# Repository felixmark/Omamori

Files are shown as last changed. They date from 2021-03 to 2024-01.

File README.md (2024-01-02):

# Omamori
Omamori is a solar-powered LED lucky and protector charm.<br>
I have got the motivation to realize this project during my time in university, when I first designed PCBs, even though I had the idea for much longer. At first, I was using Altium Designer, which was used by my university. Later since version 2.0 I switched to KiCad, which is a gem of software, which was recommended to me by Andreas.<br>
A huge thank you for helping me with soldering, designing, listening and keeping my motivation up to:<br>
Andreas, Markus, Patrick, Anna-Lena, Flopsi, Stephan and many others! ♥️<br>
<br>

## Programming

Program ATTiny 1626 via UPDI pins on the back of the PCB.  
Set the internal clock to 1MHz and use a low uploading BAUD to make sure the microcontroller can keep up.  

<br><br>

# History

A version History of the Omamori project.

[Version 0.3.1](#Version-030) \
[Version 0.3.0](#Version-030) \
[Version 0.2.1](#Version-021) \
[Version 0.2.0](#Version-020) \
[Version 0.1.0](#Version-010)
<br><br>

## Version 0.3.1

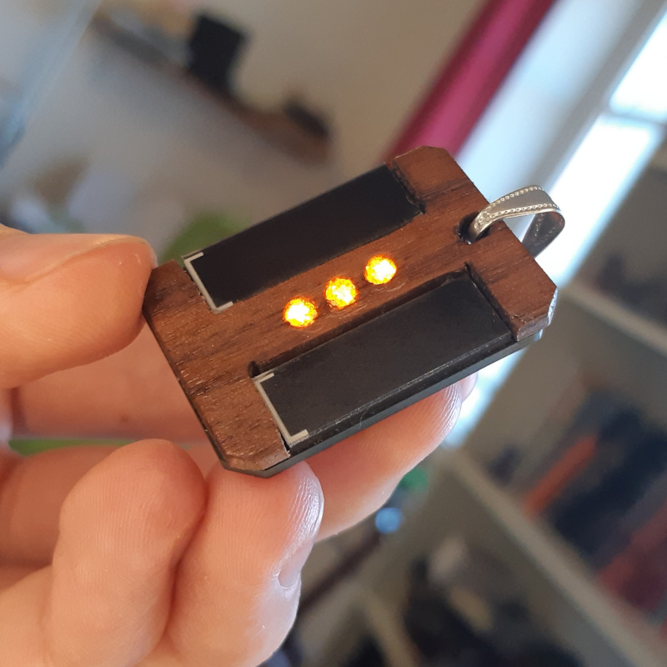
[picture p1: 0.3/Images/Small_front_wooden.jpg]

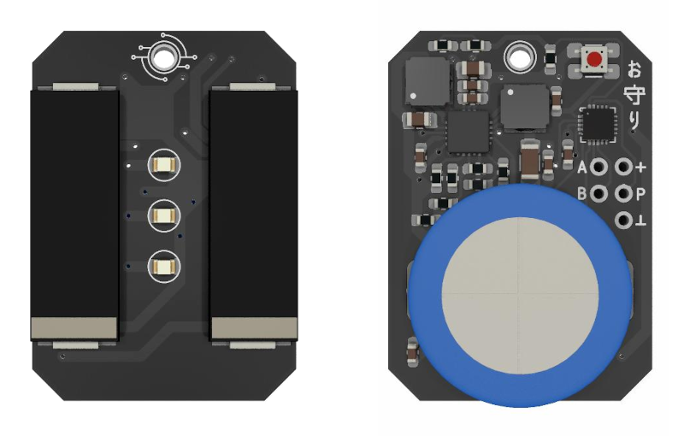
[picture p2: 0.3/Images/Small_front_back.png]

\
Hardware as in Version 0.3.0 except that a few capacitors are closer to the BQ25570 and I added a few other transistors for stability. Everything is working as expected.  
I consider this the final version for now.  

<br><br>

## Version 0.3.0

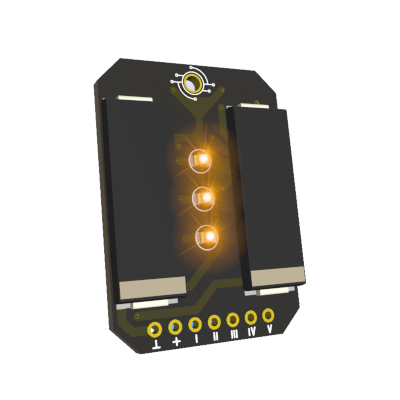
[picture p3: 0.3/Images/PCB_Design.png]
PCB v3.0

\
**MCU:** 1x ATTiny 1626 \
**Energy Harvester:** 1x BQ25570 \
**Solar Cells:** 2x KXOB25-05X3F \
**LEDS:** 3x Orange 0805 SMD LED

<br><br>

## Version 0.2.1

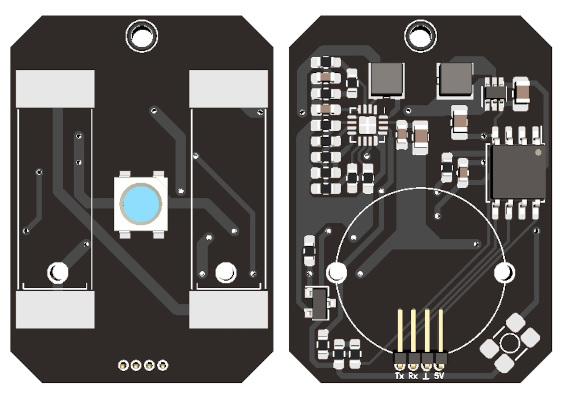
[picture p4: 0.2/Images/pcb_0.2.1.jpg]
PCB v2.1

\
Hardware as in Version 0.2.0 except a few resistors instead of the diode for measuring battery voltage and an IRLML2502 N-Channel MOSFET for switching the 5V boost converter.
This version works, but has a very short supercap lifetime. Therefore the next version has to be a lot more efficient.

<br><br>

## Version 0.2.0
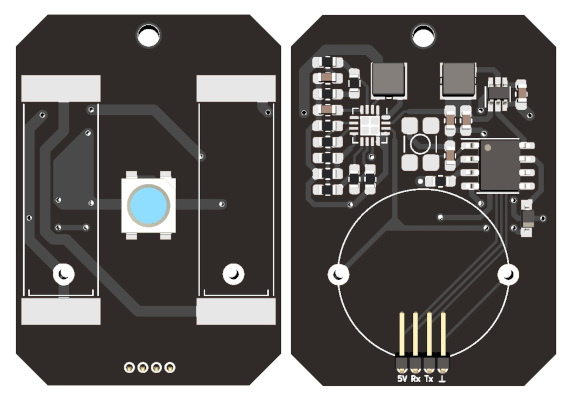
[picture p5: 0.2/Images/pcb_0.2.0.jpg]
PCB v2.0

\
**MCU:** 1x ATTiny 85 \
**Energy Harvester:** 1x BQ25504 \
**Solar Cells:** 2x KXOB25-05X3F \
**Boost Converter:** 1x TPS61222 \
**LED:** 1x SK6812 programmable RGBW LED

### Energy Harvester (BQ25504) properties

```
V_REF_SAMP    = 3.33V (R_OC1 = 6.2 MOhm + 10 MOhm = 16.2 MOhm, R_OC2 = 3.9 MOhm)
V_BAT_UV      = 2.21V (R_UV1 = 5.6 MOhm, R_UV2 = 4.3MOhm)
V_BAT_OK      = 2.27V (R_OK1 = 3.3 MOhm, R_OK2 = 2.7 MOhm, R_OK3 = 3.3 MOhm)
V_BAT_OK_HYST = 3.52V
V_BAT_OV      = 5.42V (R_OV1 = 3.6 MOhm, R_OV2 = 6.8 MOhm)
```

<br><br>

## Version 0.1.0
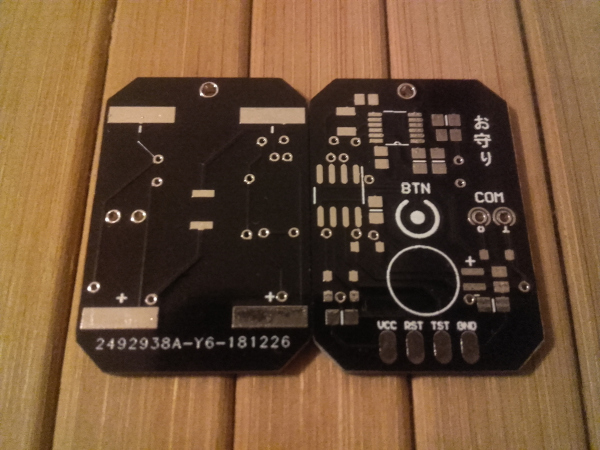
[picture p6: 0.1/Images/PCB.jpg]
PCB v1.0

\
**MCU:** 1x MSP430G2210 \
**Energy Harvester:** 1x LTC3105 \
**Solar Cells:** 2x KXOB22-04X3L 1.5Vmpp \
**LED:** 1x Natural White LED

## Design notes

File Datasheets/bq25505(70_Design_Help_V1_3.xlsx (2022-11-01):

User Input | VBIAS | 1.21 | V
Fixed
 | Comparator threshold for VSTOR of charger. |  |  |  |  | Comparator threshold voltages indicating when |  |  |  |  | For the bq25570 only, comparator threshold |  |  |  |  | Maximum power point threshold, e.g. ~0.7-0.8 of
 | Typically the max storage element voltage, |  |  |  |  | VSTOR has risen above VBAT_OK_HYST or fallen |  |  |  |  | for VOUT of buck converter. |  |  |  |  | solar panel's open circuit voltage.
 | e.g. 4.2V for LiIon battery. |  |  |  |  | below VBAT_OK.
 | VBAT_UV < VBAT_OV < 5.5V |  |  |  |  | VBAT_OV > VBAT_OK_HYST > VBAT_UV |  |  |  |  | 1.3V < VOUT < VBAT_OV |  |  |  |  | MPPT
Desired |  |  |  |  |  | RSUM1 | 13 | MW |  |  |  |  |  |  |  | RSUM1 | 20 | MW
Desired | RSUM1 | 13 | MW |  |  | VBAT_OK | 2 | V | > VBAT_UV |  | RSUM1 | 13 | MW |  |  | VIN_DC(OC) | 3 | V | Open Circuit Volts
Desired | VBAT_OV | 5.5 | V |  |  | VBAT_OK_HYST | 2.5 | V | > VBAT_OK |  | VOUT | 1.8 | V |  |  | VREF_SAMP | 2.4 | V | MPP voltage
 |  |  |  |  |  |  |  | closest 1% resistor1 |  |  |  |  |  |  |  |  |  | closest 1% resistor1
 |  |  | closest 1% resistor1 |  |  |  | Exact | < | > |  |  |  | closest 1% resistor1 |  |  |  | Exact | < | >
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

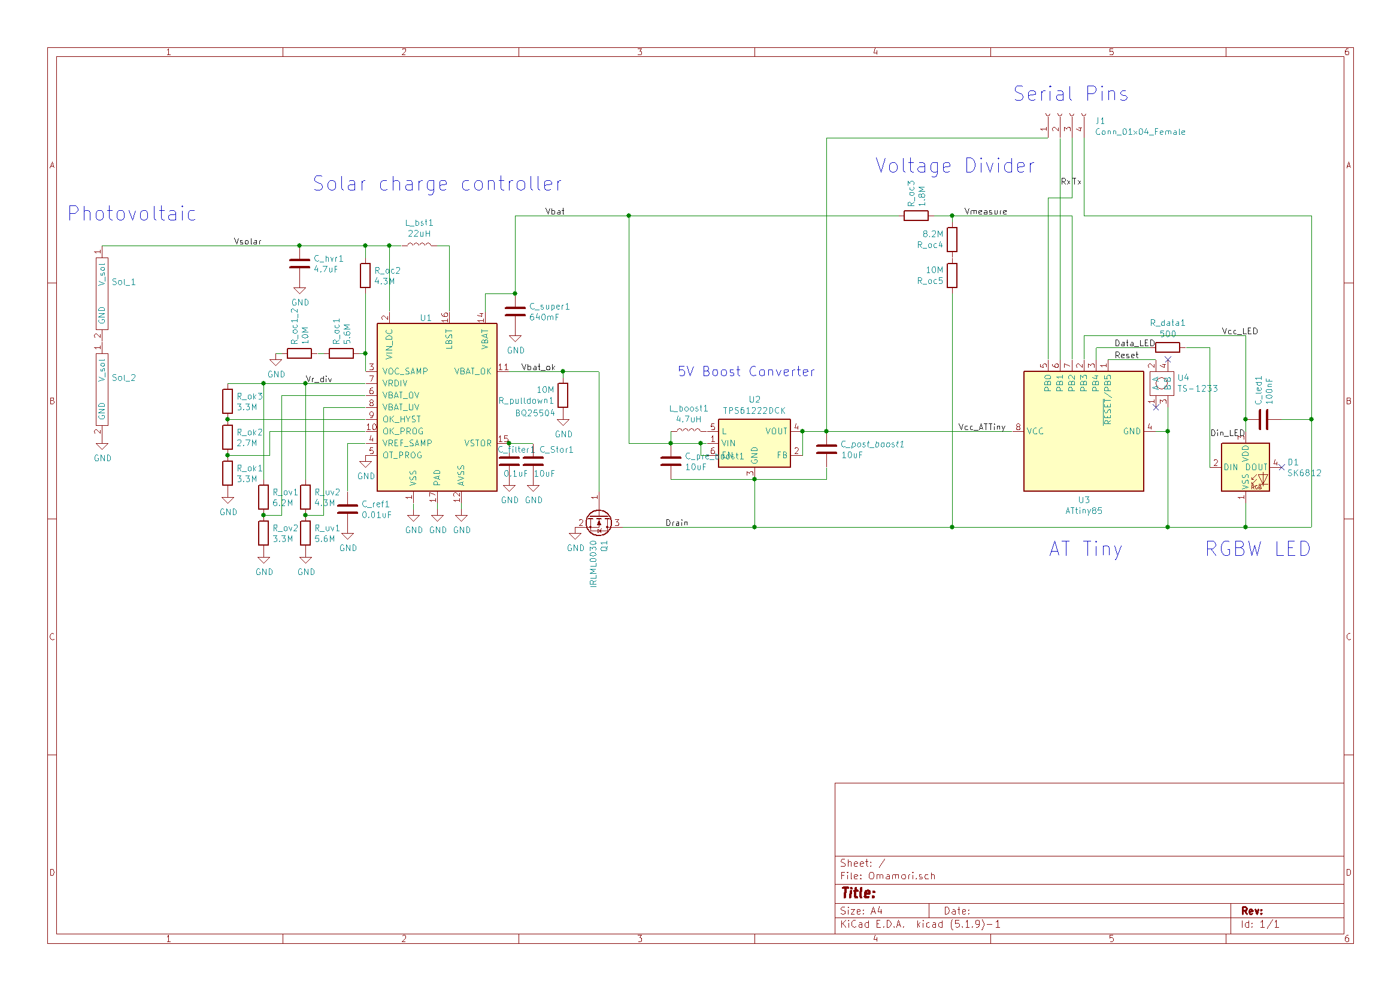
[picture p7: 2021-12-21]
0.2/Images/schematic_0.2.1.png

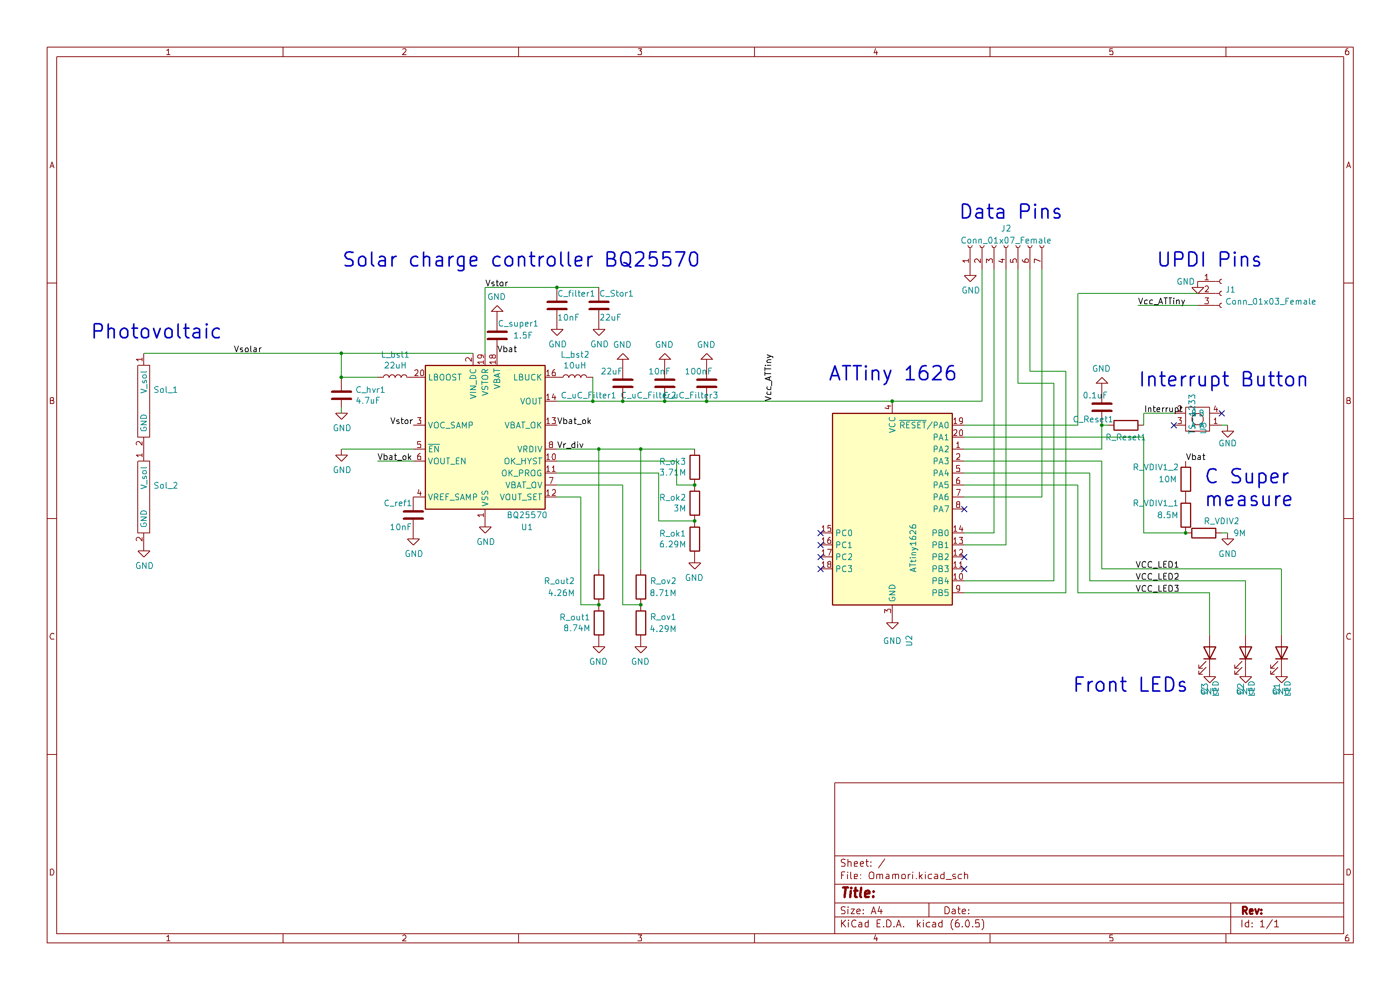
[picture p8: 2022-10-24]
0.3/Images/Schematic.png

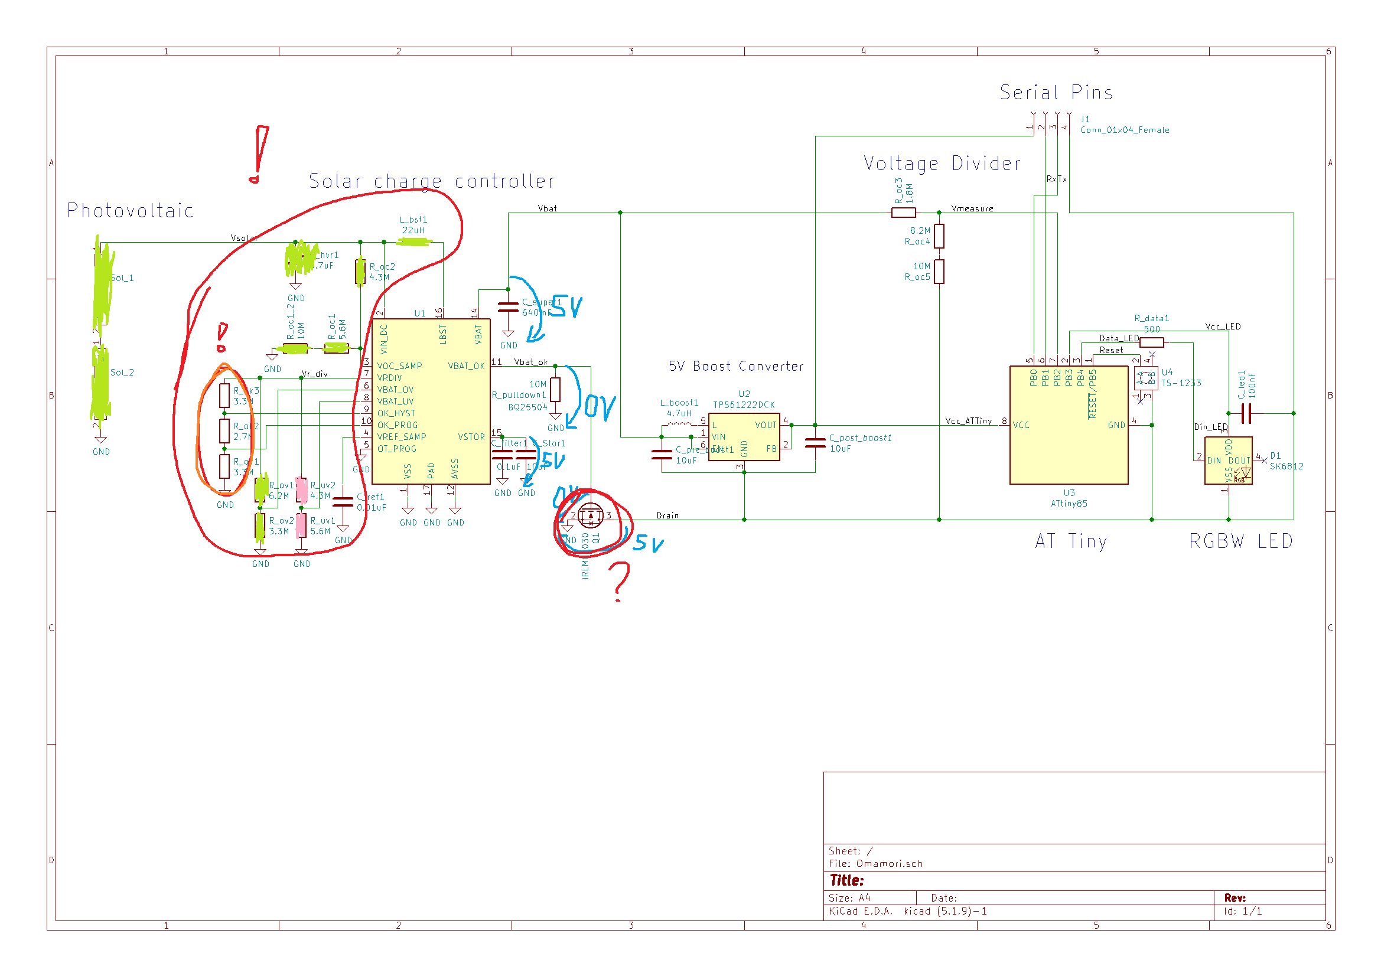
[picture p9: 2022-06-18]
0.2/Images/schematic_0.2.1 - Kopie.png

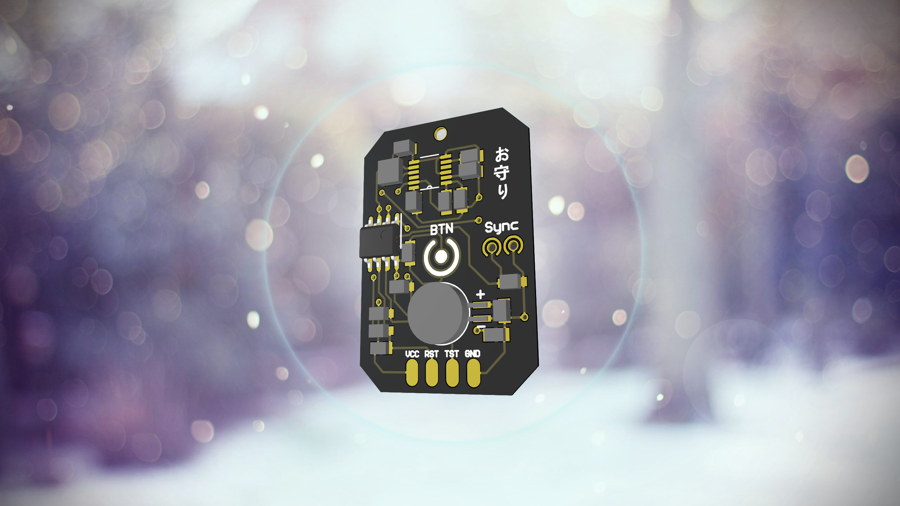
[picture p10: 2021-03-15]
0.1/Images/PCB_design.jpg

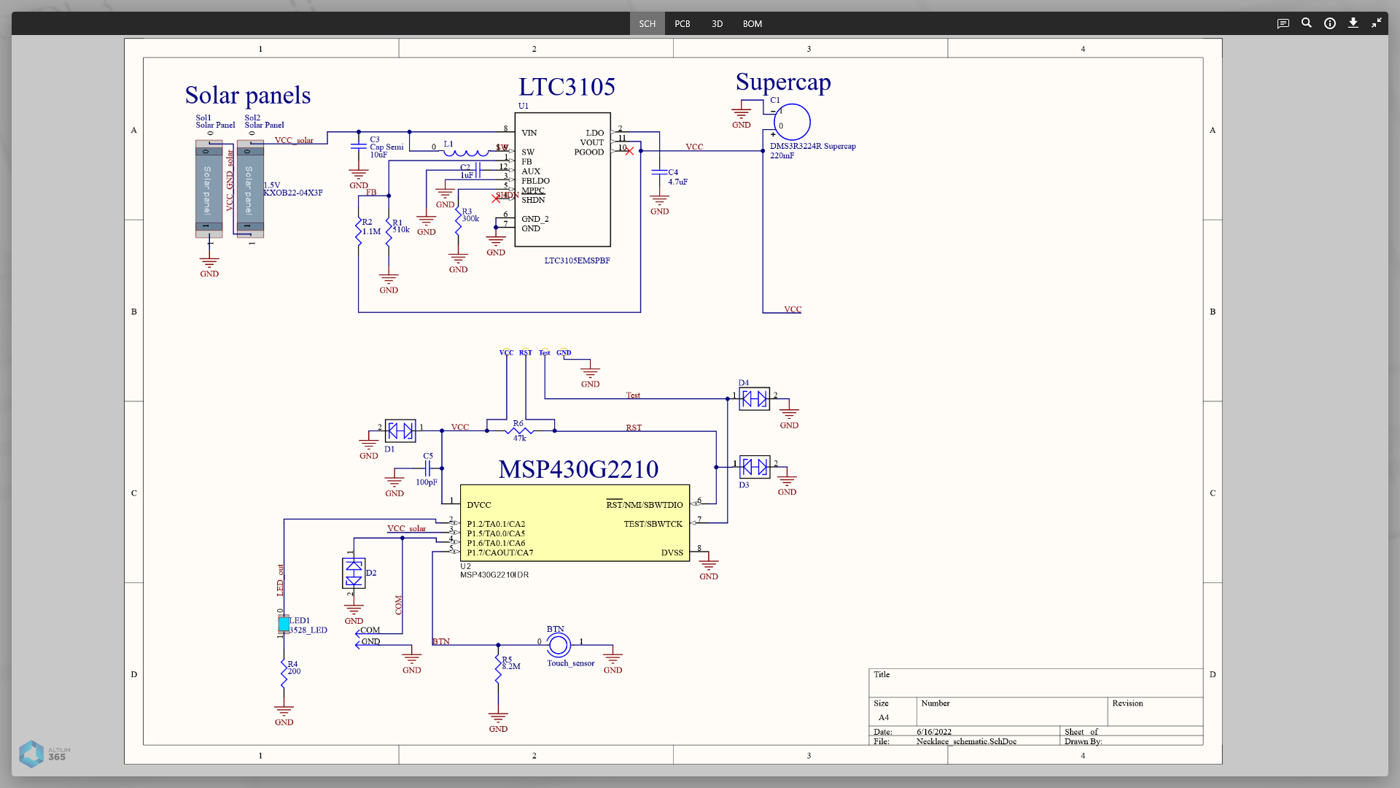
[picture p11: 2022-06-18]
0.1/Images/Schematic.png

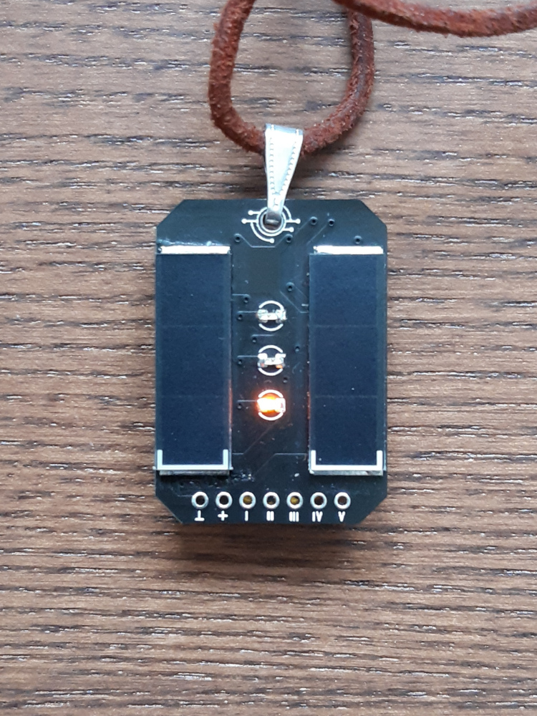
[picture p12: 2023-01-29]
0.3/Images/photo_front.jpg

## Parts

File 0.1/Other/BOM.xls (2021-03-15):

Comment | Designator | Footprint | LibRef | Quantity | Value
Touch_sensor | BTN | Touch_sensor | Touch_sensor | 1
DMS3R3224R Supercap | C1 | DMS3R3224R Supercap | DMS3R3224R Supercap | 1
Capacitor | C2, C3, C4, C5 | C0805 | Cap Semi | 4 | 1uF, 10uF, 4.7uF, 100pF
COM | COM | Synchronizer | COM | 1
TVS Diode | D1, D2, D3, D4 | ESD Protection Diode | ESD-Diode | 4
L | L1 | Inductivity | Inductivity | 1
LED | LED1 | 3528_LED | 3528_LED | 1
R | R1, R2, R3, R4, R5, R6 | 0805_N | Res3 | 6 | 510k, 1.1M, 300k, 200, 8.2M, 47k
Solar_panel | Sol1, Sol2 | Solarzelle | Solar_Panel | 2
LTC3105EMSPBF | U1 | SOP65P490X110-12N | LTC3105EMSPBF | 1
MSP430G2210IDR | U2 | MSP430G2210 | MSP430G2210IDR | 1
Program_connector | U3 | Program_connector | Program_connector | 1

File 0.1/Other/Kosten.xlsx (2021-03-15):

Kosten
Teil | Gekauft bei | Anzahl | Preis | Summe | Gesamt | Pro Stück
Korchip DMS3R3224R Doppelschicht-Kondensator 0.22 F 3.3 V (Ø x H) 6.8 mm x 1.4 mm 1 St. | Conrad | 1 | €1.29 | €1.29 | €48.70 | €14.64
Texas Instruments MSP430G2210ID Embedded-Mikrocontroller SOIC-8 16-Bit 16 MHz Anzahl I/O 4 | Conrad | 1 | €1.49 | €1.49
Solarzelle IXYS KXOB22-04X3L=KXOB22-04X3F 1.5 V/DC 44 mA 1 St. (L x B x H) 22 x 7 x 1.8 mm | Conrad | 2 | €4.19 | €8.38
SMD LED Ice blue 3528 | Aliexpress | 50 | €0.02 | €1.24
LTC3105 400mA Step-Up DC/DC Converter with Maximum Power Point Control and 250mV Start-Up | Aliexpress | 5 | €2.85 | €14.25
Bourns SRN3010-100M Induktivität abgeschirmt SMD 10 µH 0.9 A | Conrad | 5 | €0.39 | €1.95
Infineon Technologies IRLML2502TRPBF MOSFET 1 N-Kanal 1.25 W SOT-23 | Conrad | 5 | €0.22 | €1.10
PCB | Elecrow | 10 | €1.90 | €19.00
 |  |  |  | €0.00
 |  |  |  | €0.00
 |  |  |  | €0.00
 |  |  |  | €0.00
 |  |  |  | €0.00
 |  |  |  | €0.00
 |  |  |  | €0.00
 |  |  |  | €0.00
 |  |  |  | €0.00
 |  |  |  | €0.00
 |  |  |  | €0.00
 |  |  |  | €0.00
 |  |  |  | €0.00
 |  |  |  | €0.00
 |  |  |  | €0.00
 |  |  |  | €0.00
 |  |  |  | €0.00
 |  |  |  | €0.00
 |  |  |  | €0.00
 |  |  |  | €0.00
 |  |  |  | €0.00
 |  |  |  | €0.00
 |  |  |  | €0.00
 |  |  |  | €0.00
 |  |  |  | €0.00
 |  |  |  | €0.00
 |  |  |  | €0.00
 |  |  |  | €0.00
 |  |  |  | €0.00
 |  |  |  | €0.00
 |  |  |  | €0.00
 |  |  |  | €0.00
 |  |  |  | €0.00

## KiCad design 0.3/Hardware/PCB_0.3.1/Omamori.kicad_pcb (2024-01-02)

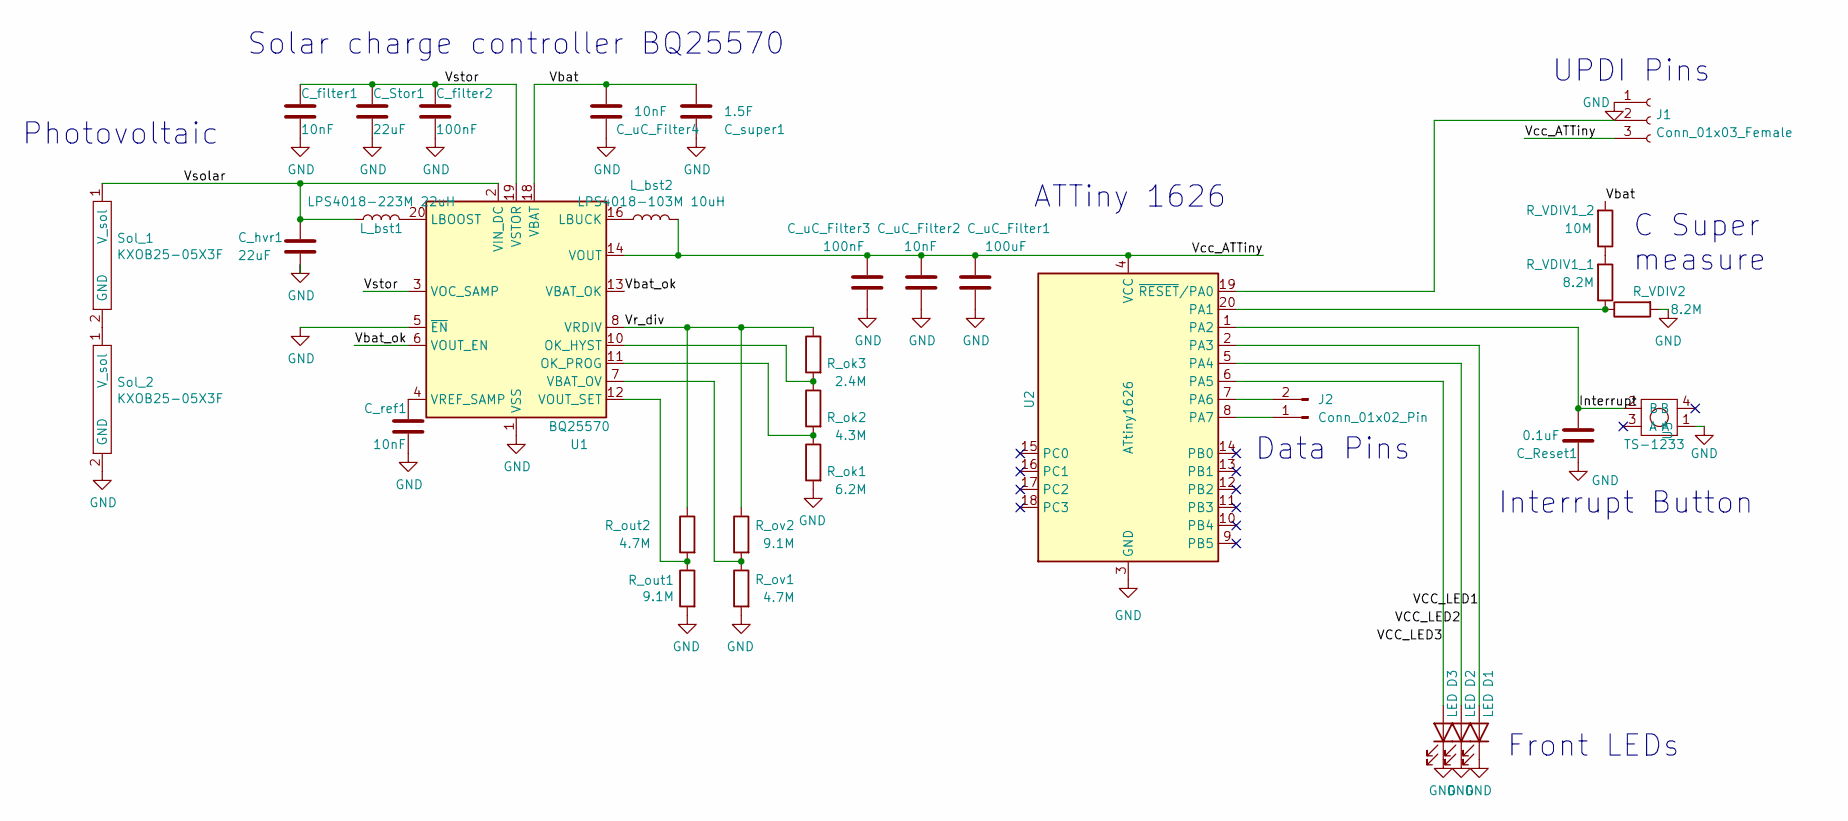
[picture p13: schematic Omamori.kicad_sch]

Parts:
C_Reset1: 0.1uF; C_0603_1608Metric_Pad1.08x0.95mm_HandSolder
C_Stor1: 22uF; C_0805_2012Metric_Pad1.18x1.45mm_HandSolder
C_filter1: 10nF; C_0603_1608Metric_Pad1.05x0.95mm_HandSolder
C_filter2: 100nF; C_0603_1608Metric_Pad1.08x0.95mm_HandSolder
C_hvr1: 22uF; C_0805_2012Metric_Pad1.18x1.45mm_HandSolder
C_ref1: 10nF; C_0603_1608Metric_Pad1.08x0.95mm_HandSolder
C_super1: 1.5F; Supercap_1F
C_uC_Filter1: 100uF; C_1206_3216Metric_Pad1.33x1.80mm_HandSolder
C_uC_Filter2, C_uC_Filter4: 10nF; C_0603_1608Metric_Pad1.08x0.95mm_HandSolder
C_uC_Filter3: 100nF; C_0603_1608Metric_Pad1.08x0.95mm_HandSolder
D1, D2, D3: LED; LED_0805_2012Metric
J1: Conn_01x03_Female; PinHeader_1x03_P2.54mm_Vertical
J2: Conn_01x02_Pin; PinHeader_1x02_P2.54mm_Vertical
L_bst1: LPS4018-223M 22uH; L_Coilcraft_LPS4018
L_bst2: LPS4018-103M 10uH; L_Coilcraft_LPS4018
R_VDIV1_1, R_VDIV2: 8.2M; R_0603_1608Metric_Pad0.98x0.95mm_HandSolder
R_VDIV1_2: 10M; R_0603_1608Metric_Pad0.98x0.95mm_HandSolder
R_ok1: 6.2M; R_0603_1608Metric_Pad1.05x0.95mm_HandSolder
R_ok2: 4.3M; R_0603_1608Metric_Pad1.05x0.95mm_HandSolder
R_ok3: 2.4M; R_0603_1608Metric_Pad1.05x0.95mm_HandSolder
R_out1: 9.1M; R_0603_1608Metric_Pad1.05x0.95mm_HandSolder
R_out2: 4.7M; R_0603_1608Metric_Pad1.05x0.95mm_HandSolder
R_ov1: 4.7M; R_0603_1608Metric_Pad1.05x0.95mm_HandSolder
R_ov2: 9.1M; R_0603_1608Metric_Pad1.05x0.95mm_HandSolder
Sol_1, Sol_2: KXOB25-05X3F
U1: BQ25570; QFN-20-1EP_3.5x3.5mm_P0.5mm_EP2x2mm
U2: ATtiny1626; VQFN-20-1EP_3x3mm_P0.4mm_EP1.7x1.7mm
U3: TS-1233

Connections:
/Interrupt: C_Reset1.2, U2.1 (PA2), U3.2 (B)
/VCC_LED1: D1.2 (A), U2.2 (PA3)
/VCC_LED2: D2.2 (A), U2.5 (PA4)
/VCC_LED3: D3.2 (A), U2.6 (PA5)
/Vbat: C_super1.2, C_uC_Filter4.1, R_VDIV1_2.2, U1.18 (VBAT)
/Vbat_ok: U1.6 (VOUT_EN), U1.13 (VBAT_OK)
/Vcc_ATTiny: C_uC_Filter1.1, C_uC_Filter2.1, C_uC_Filter3.1, J1.3, L_bst2.2, U1.14 (VOUT), U2.4 (VCC)
/Vr_div: R_ok3.1, R_out2.1, R_ov2.1, U1.8 (VRDIV)
/Vsolar: C_hvr1.1, L_bst1.1, Sol_1.1 (V_sol), U1.2 (VIN_DC)
/Vstor: C_Stor1.1, C_filter1.1, C_filter2.1, U1.3 (VOC_SAMP), U1.19 (VSTOR)
GND: C_Reset1.1, C_Stor1.2, C_filter1.2, C_filter2.2, C_hvr1.2, C_ref1.2, C_super1.1, C_uC_Filter1.2, C_uC_Filter2.2, C_uC_Filter3.2, C_uC_Filter4.2, D1.1 (K), D2.1 (K), D3.1 (K), J1.1, R_VDIV2.2, R_ok1.2, R_out1.2, R_ov1.2, Sol_2.2 (GND), U1.1 (VSS), U1.5 (~EN), U1.9 (VSS), U1.15 (VSS), U1.17 (VSS), U1.21 (VSS), U2.3 (GND), U2.21 (GND), U3.1 (A)
unnamed: J1.2, U2.19 (~RESET/PA0)
unnamed: J2.1, U2.8 (PA7)
unnamed: J2.2, U2.7 (PA6)
unnamed: R_VDIV1_1.2, R_VDIV1_2.1
unnamed: Sol_1.2 (GND), Sol_2.1 (V_sol)
unnamed: L_bst1.2, U1.20 (LBOOST)
unnamed: L_bst2.1, U1.16 (LBUCK)
unnamed: R_ok2.1, R_ok3.2, U1.10 (OK_HYST)
unnamed: R_ok1.1, R_ok2.2, U1.11 (OK_PROG)
unnamed: R_ov1.1, R_ov2.2, U1.7 (VBAT_OV)
unnamed: R_out1.1, R_out2.2, U1.12 (VOUT_SET)
unnamed: C_ref1.1, U1.4 (VREF_SAMP)
unnamed: R_VDIV1_1.1, R_VDIV2.1, U2.20 (PA1)

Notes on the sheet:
UPDI Pins
C Super measure
Front LEDs
Photovoltaic
Data Pins
Interrupt Button
Solar charge controller BQ25570
ATTiny 1626

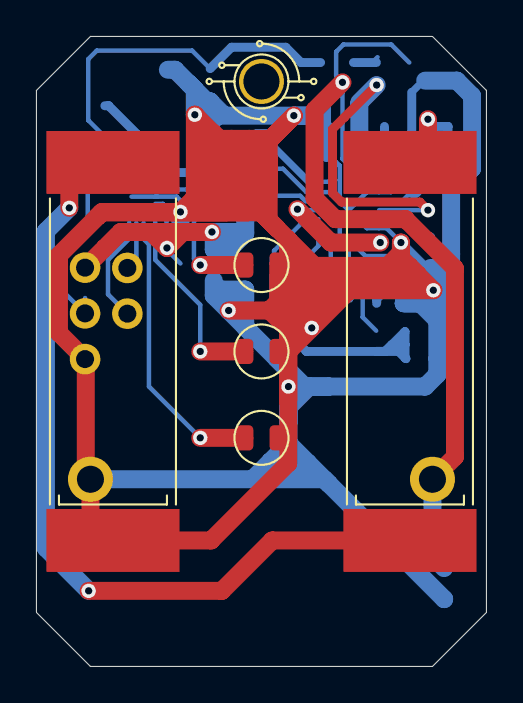
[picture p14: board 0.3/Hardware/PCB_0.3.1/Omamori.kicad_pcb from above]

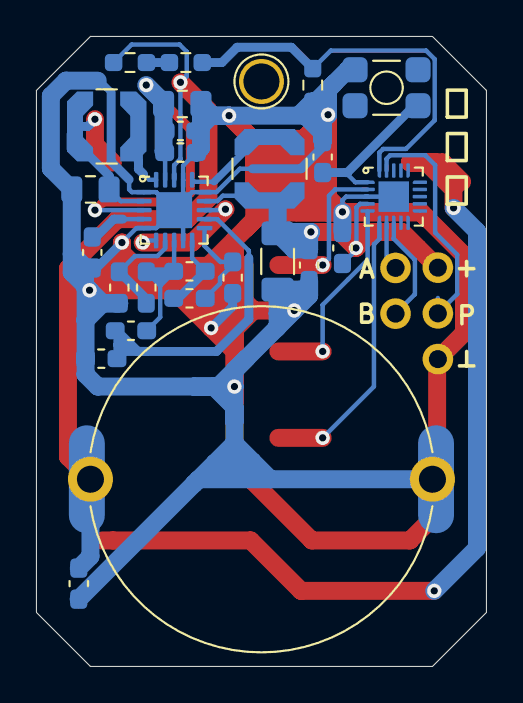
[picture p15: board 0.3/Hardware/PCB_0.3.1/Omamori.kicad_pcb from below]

Board: 2 copper layers, 25.0 x 35.0 mm, 33 parts (28 on the bottom side), 24 nets.

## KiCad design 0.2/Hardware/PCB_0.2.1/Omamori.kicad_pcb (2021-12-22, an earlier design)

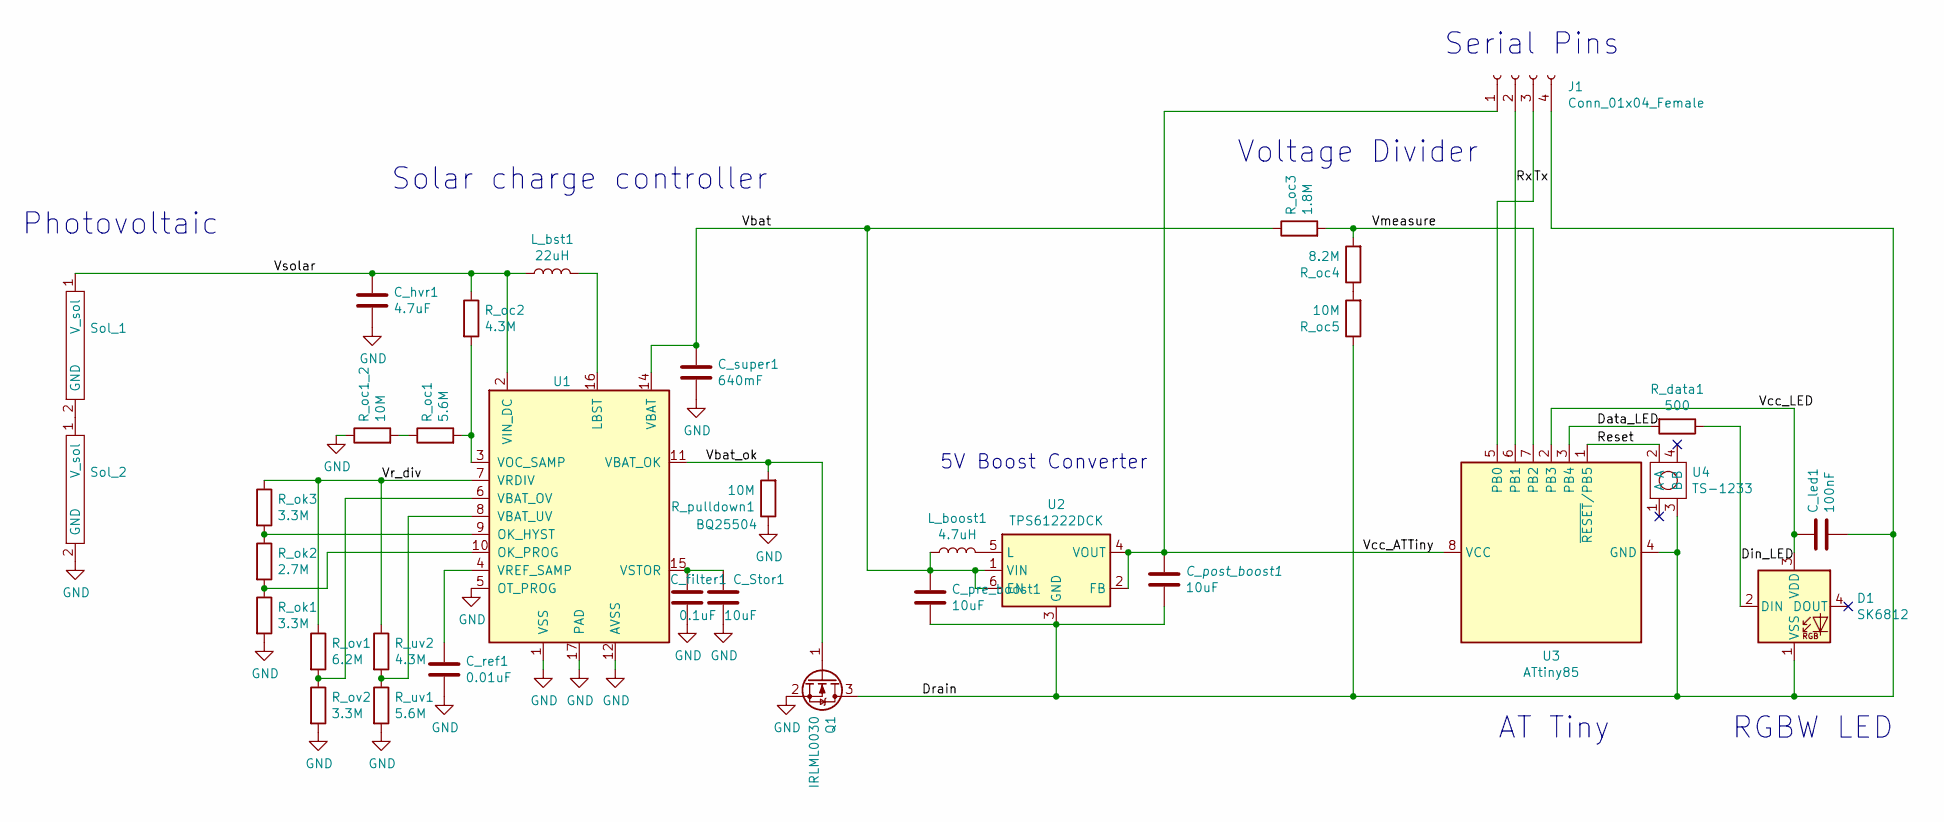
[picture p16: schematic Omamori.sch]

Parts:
C_Stor1: 10uF; C_0805_2012Metric_Pad1.18x1.45mm_HandSolder
C_filter1: 0.1uF; C_0603_1608Metric_Pad1.05x0.95mm_HandSolder
C_hvr1: 4.7uF; C_0805_2012Metric_Pad1.18x1.45mm_HandSolder
C_led1: 100nF; C_0603_1608Metric_Pad1.05x0.95mm_HandSolder
C_post_boost1: 10uF; C_0805_2012Metric_Pad1.18x1.45mm_HandSolder
C_pre_boost1: 10uF; C_0805_2012Metric_Pad1.18x1.45mm_HandSolder
C_ref1: 0.01uF; C_0603_1608Metric_Pad1.05x0.95mm_HandSolder
C_super1: 640mF; Supercap
D1: SK6812; LED_SK6812_PLCC4_5.0x5.0mm_P3.2mm
J1: Conn_01x04_Female; PinHeader_1x04_P1.27mm_Horizontal
L_boost1: 4.7uH; L_Wuerth_MAPI-3015
L_bst1: 22uH; L_Wuerth_MAPI-3015
Q1: IRLML0030; SOT-23
R_data1: 500; R_0603_1608Metric_Pad1.05x0.95mm_HandSolder
R_oc1: 5.6M; R_0603_1608Metric_Pad0.98x0.95mm_HandSolder
R_oc1_2: 10M; R_0603_1608Metric_Pad1.05x0.95mm_HandSolder
R_oc2: 4.3M; R_0603_1608Metric_Pad1.05x0.95mm_HandSolder
R_oc3: 1.8M; R_0603_1608Metric_Pad0.98x0.95mm_HandSolder
R_oc4: 8.2M; R_0603_1608Metric_Pad0.98x0.95mm_HandSolder
R_oc5: 10M; R_0603_1608Metric_Pad0.98x0.95mm_HandSolder
R_ok1, R_ok3: 3.3M; R_0603_1608Metric_Pad1.05x0.95mm_HandSolder
R_ok2: 2.7M; R_0603_1608Metric_Pad1.05x0.95mm_HandSolder
R_ov1: 6.2M; R_0603_1608Metric_Pad1.05x0.95mm_HandSolder
R_ov2: 3.3M; R_0603_1608Metric_Pad1.05x0.95mm_HandSolder
R_pulldown1: 10M; R_0603_1608Metric_Pad1.05x0.95mm_HandSolder
R_uv1: 5.6M; R_0603_1608Metric_Pad1.05x0.95mm_HandSolder
R_uv2: 4.3M; R_0603_1608Metric_Pad1.05x0.95mm_HandSolder
Sol_1, Sol_2: KXOB25-05X3F
U1: BQ25504; VQFN-16-1EP_3x3mm_P0.5mm_EP1.8x1.8mm
U2: TPS61222DCK; Texas_R-PDSO-G6
U3: ATtiny85; SOIC-8_5.275x5.275mm_P1.27mm
U4: TS-1233

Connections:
/Data_LED: R_data1.2, U3.3 (PB4)
/Din_LED: D1.2 (DIN), R_data1.1
/Drain: C_led1.2, C_post_boost1.2, C_pre_boost1.2, D1.1 (VSS), J1.4, Q1.3 (D), R_oc5.1, U2.3 (GND), U3.4 (GND), U4.3 (B)
/Reset: U3.1 (~RESET~/PB5), U4.2 (A)
/Rx: J1.2, U3.6 (PB1)
/Tx: J1.3, U3.5 (PB0)
/Vbat: C_pre_boost1.1, C_super1.1, L_boost1.1, R_oc3.1, U1.14 (VBAT), U2.1 (VIN), U2.6 (EN)
/Vbat_ok: Q1.1 (G), R_pulldown1.2, U1.11 (VBAT_OK)
/Vcc_ATTiny: C_post_boost1.1, J1.1, U2.2 (FB), U2.4 (VOUT), U3.8 (VCC)
/Vcc_LED: C_led1.1, D1.3 (VDD), U3.2 (PB3)
/Vmeasure: R_oc3.2, R_oc4.2, U3.7 (PB2)
/Vr_div: R_ok3.1, R_ov1.1, R_uv2.1, U1.7 (VRDIV)
/Vsolar: C_hvr1.1, L_bst1.1, R_oc2.1, Sol_1.1 (V_sol), U1.2 (VIN_DC)
GND: C_Stor1.2, C_filter1.2, C_hvr1.2, C_ref1.2, C_super1.2, Q1.2 (S), R_oc1_2.1, R_ok1.2, R_ov2.2, R_pulldown1.1, R_uv1.2, Sol_2.2 (GND), U1.1 (VSS), U1.5 (OT_PROG), U1.12 (AVSS), U1.13 (VSS), U1.17 (PAD)
unnamed: C_Stor1.1, C_filter1.1, U1.15 (VSTOR)
unnamed: C_ref1.1, U1.4 (VREF_SAMP)
unnamed: L_boost1.2, U2.5 (L)
unnamed: L_bst1.2, U1.16 (LBST)
unnamed: R_oc1.1, R_oc1_2.2
unnamed: R_oc1.2, R_oc2.2, U1.3 (VOC_SAMP)
unnamed: R_oc4.1, R_oc5.2
unnamed: R_ok1.1, R_ok2.2, U1.10 (OK_PROG)
unnamed: R_ok2.1, R_ok3.2, U1.9 (OK_HYST)
unnamed: R_ov1.2, R_ov2.1, U1.6 (VBAT_OV)
unnamed: R_uv1.1, R_uv2.2, U1.8 (VBAT_UV)
unnamed: Sol_1.2 (GND), Sol_2.1 (V_sol)

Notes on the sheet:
5V Boost Converter
Voltage Divider
Serial Pins
AT Tiny
RGBW LED
Solar charge controller
Photovoltaic

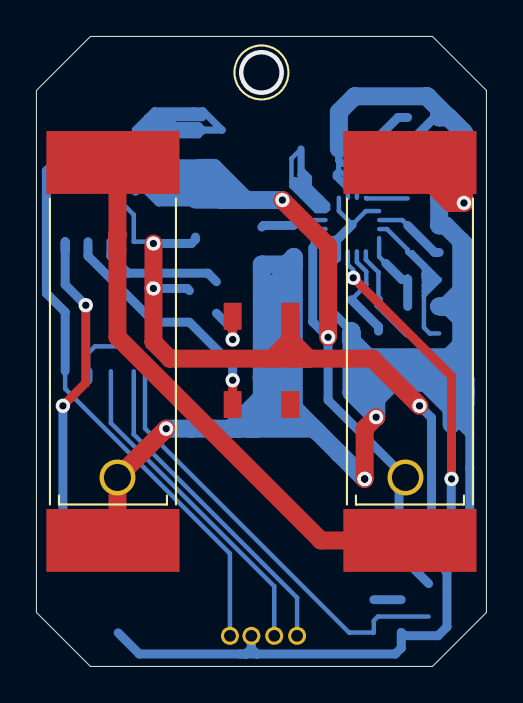
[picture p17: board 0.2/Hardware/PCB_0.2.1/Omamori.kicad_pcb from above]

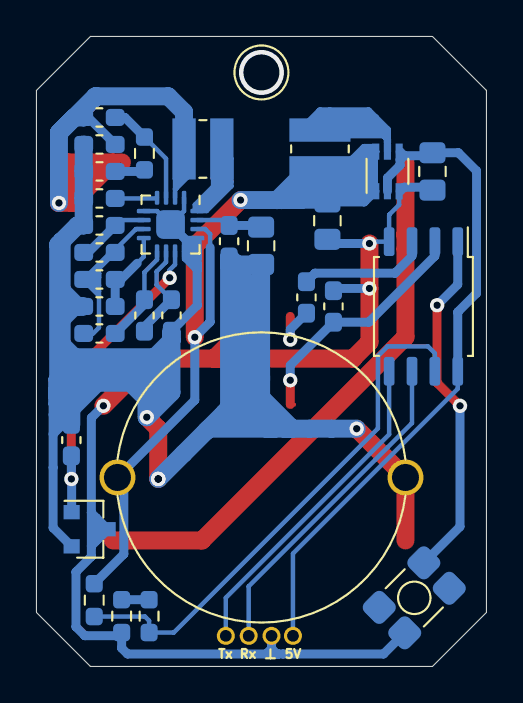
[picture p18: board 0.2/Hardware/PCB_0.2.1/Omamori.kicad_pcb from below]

Board: 2 copper layers, 25.0 x 35.0 mm, 34 parts (31 on the bottom side), 26 nets.

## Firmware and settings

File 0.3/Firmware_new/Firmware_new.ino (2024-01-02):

/*
  Omamori Firmware v1.1

  Author: Felix Mark
  Date:   23.10.2022
*/

// ==========================================================================================================================
// Includes
// ==========================================================================================================================
#include <avr/interrupt.h> // Used for enabling interrupts (especially by RTC)
#include <avr/sleep.h>     // Used for sleeping

// ==========================================================================================================================
// Defines
// ==========================================================================================================================
#define PIN_SUPERCAP_MEASUREMENT PIN_A1 // MEASURE SUPERCAP
#define PIN_BUTTON PIN_A2               // BUTTON
#define PIN_LED1 PIN_A3                 // TOP LED
#define PIN_LED2 PIN_A4                 // MID LED
#define PIN_LED3 PIN_A5                 // BOT LED

#define NUM_SIGMOID_VALUES 105 // amount
#define BLINK_DELAY 100        // ms
#define ANIMATION_DELAY 5      // ms
#define SLEEP_SECONDS 15       // s
#define ANIMATION_OCCURS 10    // play animation every nth time

// 4.75V and above = 4095 while 1.8V is 1820
#define ADC_VALUE_1_3_CHARGED 2720
#define ADC_VALUE_2_3_CHARGED 3650

// ==========================================================================================================================
// Variables
// ==========================================================================================================================
int soc = 0;                                    // Store SOC measurement (State of charge)
int operation_mode = 1;                         // Track operation mode
volatile bool button_pressed_interrupt = false; // Flag for button press ISR

// ==========================================================================================================================
// Constants
// ==========================================================================================================================
static uint8_t SIGMOID[NUM_SIGMOID_VALUES] = {
    0, 1, 2, 3, 4, 5, 6, 7, 8, 9, 10, 11, 12, 13, 15, 17, 19, 21, 23, 25, 27, 30, 33, 36, 39,
    42, 46, 50, 54, 58, 63, 68, 73, 79, 84, 90, 96, 102, 108, 115, 121, 128, 134, 140, 146, 153, 159, 165, 170, 176,
    181, 186, 191, 196, 200, 205, 208, 212, 216, 219, 222, 225, 227, 230, 232, 234, 236, 237, 239, 240, 242, 243, 244, 245, 246,
    247, 248, 248, 249, 249, 250, 250, 251, 251, 252, 252, 252, 252, 253, 253, 253, 253, 253, 254, 254, 254, 254, 254, 254, 255,
    255, 255, 255, 255, 255};

// ==========================================================================================================================
// Function declarations
// ==========================================================================================================================
void play_led_wave(uint8_t mode);

// ==========================================================================================================================
// Setup
// ==========================================================================================================================
void setup()
{
    // Disable interrupts before changing them
    cli();

    // Set all pins to low power mode
    for (uint8_t pin = 0; pin < 8; pin++)
    {
        *((uint8_t *)&PORTA + 0x10 + pin) |= 1 << PORT_PULLUPEN_bp; // Enable all pullups on port A
        *((uint8_t *)&PORTB + 0x10 + pin) |= 1 << PORT_PULLUPEN_bp; // Enable all pullups on port B
        *((uint8_t *)&PORTC + 0x10 + pin) |= 1 << PORT_PULLUPEN_bp; // Enable all pullups on port C
        (&PORTA.PIN0CTRL)[pin] = PORT_ISC_INPUT_DISABLE_gc;         // Disable interrupt and digital input buffer on port A
        (&PORTB.PIN0CTRL)[pin] = PORT_ISC_INPUT_DISABLE_gc;         // Disable interrupt and digital input buffer on port B
        (&PORTC.PIN0CTRL)[pin] = PORT_ISC_INPUT_DISABLE_gc;         // Disable interrupt and digital input buffer on port C
    }
    pinMode(PIN_SUPERCAP_MEASUREMENT, INPUT);
    //pinMode(PIN_BUTTON, INPUT_PULLUP);
    pinMode(PIN_LED1, OUTPUT);
    pinMode(PIN_LED2, OUTPUT);
    pinMode(PIN_LED3, OUTPUT);

    // Wait for all register to be synchronized
    while (RTC.STATUS > 0);

    // RTC configuration
    RTC.PER = 1024 * SLEEP_SECONDS;                                               // n secs between wakes.
    RTC.INTCTRL = 0 << RTC_CMP_bp | 1 << RTC_OVF_bp;                              // Overflow interrupt
    RTC.CTRLA = RTC_PRESCALER_DIV1_gc | 1 << RTC_RTCEN_bp | 1 << RTC_RUNSTDBY_bp; // No Prescaler + Enable RTC + Run in standby
    RTC.CLKSEL = RTC_CLKSEL_INT1K_gc;                                             // 32KHz divided by 32, i.e run at 1.024kHz

    // Set ADC resolution
    analogReference(VDD);
    analogReadResolution(12);

    // Set falling edge detection on button press
    PORTA.PIN2CTRL = PORT_ISC_FALLING_gc;  // Enable pin A2 falling edge interrupts
    PORTA.PIN2CTRL |= PORT_PULLUPEN_bm;     // Enable pin A2 pull-up resistor
    PORTA.DIR &= ~PIN2_bm;               // Set pin A2 as INPUT  -> Internal pull-up required for async button interrupt

    // Enable interrupts
    sei();
}

// ==========================================================================================================================
// Loop
// ==========================================================================================================================
void loop()
{
    // On button press change mode
    if (button_pressed_interrupt)
    {
        button_pressed_interrupt = false;
        operation_mode = (operation_mode + 1) % 3;
        blink_led(operation_mode + 1);
        delay(200);
        blink_led(operation_mode + 1);
    }
    else
    {
        // Check operating mode and blink accordingly
        if (operation_mode > 0)
        {
            // Turn on ADC and wait for 10 ms
            ADC0_CTRLA |= ADC_ENABLE_bm;
            delay(10);
            read_soc();
            if (operation_mode == 1)
            {
                /*
                for (int i = 0; i < soc / 1000; ++i) { blink_led(0); delay(400); }
                delay(1000); 
                for (int i = 0; i < soc % 1000 / 100; ++i) { blink_led(1); delay(400); }
                delay(1000);
                for (int i = 0; i < soc % 100 / 10; ++i) { blink_led(2); delay(400); }
                delay(1000);
                for (int i = 0; i < soc % 10; ++i) { blink_led(3); delay(400); }
                */
                blink_led_pretty_according_to_soc();
            }
            else if (operation_mode == 2)
            {
                if (soc <= ADC_VALUE_1_3_CHARGED)
                    play_led_wave(0);
                else if (soc <= ADC_VALUE_2_3_CHARGED)
                    play_led_wave(1);
                else
                    play_led_wave(2);
            }
        }
    }
    
    // Go to sleep
    ADC0_CTRLA &= ~ADC_ENABLE_bm;       // Turn off ADC
    set_sleep_mode(SLEEP_MODE_STANDBY); // Set standby sleep mode
    sleep_enable();                     // Enable sleeping
    sleep_cpu();                        // Sleep until woken up by ISR
}

// ==========================================================================================================================
// ISR (Interrupt Service Routine)
// ==========================================================================================================================
ISR(RTC_CNT_vect)
{
    RTC.INTFLAGS = RTC_OVF_bm;  // Wake up
}

ISR(PORTA_PORT_vect) {
    if (PORTA.INTFLAGS & PIN2_bm) {
        button_pressed_interrupt = true;
        PORTA.INTFLAGS = PIN2_bm;  // Clear interrupt flag
    }
}

// ==========================================================================================================================
// Functions
// ==========================================================================================================================
void play_led_wave(uint8_t mode = 0)
{
    int delayed = 0, delayed2 = 0;
    int a = 0, b = 0, c = 0;
    for (int i = 0; i < NUM_SIGMOID_VALUES * 2 + 140; i += 1)
    {
        a = i;
        b = delayed;
        c = delayed2;
        if (a >= NUM_SIGMOID_VALUES * 2 - 1)
        {
            a = 0;
        }
        else if (a >= NUM_SIGMOID_VALUES)
        {
            a = NUM_SIGMOID_VALUES - 1 - (a % NUM_SIGMOID_VALUES);
        }
        if (a < 0)
        {
            a = 0;
        }
        if (b >= NUM_SIGMOID_VALUES * 2 - 1)
        {
            b = 0;
        }
        else if (b >= NUM_SIGMOID_VALUES)
        {
            b = NUM_SIGMOID_VALUES - 1 - (b % NUM_SIGMOID_VALUES);
        }
        if (b < 0)
        {
            b = 0;
        }
        if (c >= NUM_SIGMOID_VALUES * 2 - 1)
        {
            c = 0;
        }
        else if (c >= NUM_SIGMOID_VALUES)
        {
            c = NUM_SIGMOID_VALUES - 1 - (c % NUM_SIGMOID_VALUES);
        }
        if (c < 0)
        {
            c = 0;
        }
        if (mode == 0)
        { // Up
            set_leds_analog(SIGMOID[c], SIGMOID[b], SIGMOID[a]);
        }
        else if (mode == 1)
        { // Center
            set_leds_analog(SIGMOID[b], SIGMOID[a] + SIGMOID[c], SIGMOID[b]);
        }
        else
        { // Down
            set_leds_analog(SIGMOID[a], SIGMOID[b], SIGMOID[c]);
        }
        delay(ANIMATION_DELAY);

        if (i >= 70)
        {
            delayed++;
        }
        if (i >= 140)
        {
            delayed2++;
        }
    }
}

void blink_led_pretty_according_to_soc()
{
    if (soc <= ADC_VALUE_1_3_CHARGED)
    {
        blink_led_pretty(3);
    }
    else if (soc <= ADC_VALUE_2_3_CHARGED)
    {
        blink_led_pretty(2);
    }
    else
    {
        blink_led_pretty(1);
    }
}

void set_leds_analog(int led1, int led2, int led3)
{
    analogWrite(PIN_LED1, led1);
    analogWrite(PIN_LED2, led2);
    analogWrite(PIN_LED3, led3);
}

void set_leds_digital(int high_low1, int high_low2, int high_low3)
{
    digitalWrite(PIN_LED1, high_low1);
    digitalWrite(PIN_LED2, high_low2);
    digitalWrite(PIN_LED3, high_low3);
}

void blink_led(uint8_t which_one)
{
    // Turn LED on, wait for BLINK_DELAY, turn LED off
    set_leds_digital(
        which_one == 1 || which_one == 0,
        which_one == 2 || which_one == 0,
        which_one == 3 || which_one == 0);
    delay(BLINK_DELAY);
    set_leds_digital(LOW, LOW, LOW);
}

void blink_led_pretty(uint8_t which_one)
{
    // Use sigmoid function to turn an led on and off
    int a = 0;
    for (int i = 0; i < NUM_SIGMOID_VALUES * 2; i += 1)
    {
        a = i;
        if (a >= NUM_SIGMOID_VALUES)
        {
            a = NUM_SIGMOID_VALUES - 1 - (a % NUM_SIGMOID_VALUES);
        }

        if (which_one == 1)
        {
            set_leds_analog(SIGMOID[a], 0, 0);
        }
        else if (which_one == 2)
        {
            set_leds_analog(0, SIGMOID[a], 0);
        }
        else if (which_one == 3)
        {
            set_leds_analog(0, 0, SIGMOID[a]);
        }
        else if (which_one == 0)
        {
            set_leds_analog(SIGMOID[a], SIGMOID[a], SIGMOID[a]);
        }
        delay(ANIMATION_DELAY * 2);
    }
}

void read_soc()
{
    // Write analog value from ADC to soc variable (0-4095)
    soc = analogRead(PIN_SUPERCAP_MEASUREMENT);
}

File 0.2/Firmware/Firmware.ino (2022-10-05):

/*
    Omamori Program v1.0
    
    Author: Felix Mark
    Date:   23.05.2021

         AT TINY PINOUT
             ______
       RST -|O     |- VCC
    LED EN -|      |- MEASURE 
       LED -|      |- RX
       GND -|______|- TX
    
    Serial Protocol:
    <cmd>:<values (if needed)>;
    
    List of commands:
    STA;                                                    // Get Status
    COL:<red byte>,<green byte>,<blue byte>,<white byte>;   // Set Color
    BAT;                                                    // Set Mode to Battery display
    DEF;                                                    // Set Mode to Default
    SLP:<1-100>;                                            // Set sleep time between blinks
*/



// ============================================================= INCLUDES
#include <Adafruit_NeoPixel.h>
#include <SoftwareSerial.h>
#include <avr/wdt.h>
#include <avr/sleep.h>
#include <avr/power.h>
#include <avr/eeprom.h>



// ============================================================= DEFINES
#define VERSION             "1.0"
#define SERIAL_BAUD         19200 // Corresponds to 2400 BAUD at 8 MHz
#define MAXIMUM_BRIGHTNESS  70
#define BLINK_ON_TIME       10
#define ANIMATION_DELAY     15
#define NUM_ELEMENTS        105
#define SERIAL_TIMEFRAME    5000
#define SERIAL_BUFFER_SIZE  30

// Pins
#define PIN_LED             PCINT4
#define PIN_LED_ENABLE      PCINT3
#define PIN_MEASUREMENT     A1
#define PIN_RX              PCINT1
#define PIN_TX              PCINT0

// Other
#define POS_RED             0
#define POS_GRN             1
#define POS_BLU             2
#define POS_WHT             3

// Modes
#define MODE_DEFAULT        0
#define MODE_BATTERY        1



// ============================================================= CONSTANTS
static uint8_t SIGMOID [NUM_ELEMENTS] = {
    1,   2,   3,   4,   5,   6,
    7,   8,   9,   10,  11,  12,  13,  14,  16,  17,  19,  21,  23,  25,  27,  30,  33,  36,  39,  42,  46,  50,  54,  58,
    63,  68,  73,  79,  84,  90,  96,  102, 108, 115, 121, 128, 134, 140, 146, 153, 159, 165, 170, 176, 181, 186, 191, 196, 200,
    205, 208, 212, 216, 219, 222, 225, 227, 230, 232, 234, 236, 237, 239, 240, 242, 243, 244, 245, 246, 247, 248, 248, 249, 249, 
    250, 250, 251, 251, 252, 252, 252, 252, 253, 253, 253, 253, 253, 254, 254, 254, 254, 254, 254, 254, 254, 254, 254, 254, 255
};



// ============================================================= VARIABLES
Adafruit_NeoPixel led = Adafruit_NeoPixel(1, PIN_LED, NEO_GRBW + NEO_KHZ800);
SoftwareSerial mySerial(PIN_RX, PIN_TX);

volatile bool awake = false;          // Used for waking up in ISR (Interrupt Service Routine)
uint8_t current_sleep_cycles = 1;     // Between 1 and 10 cycles = 8 to 80 seconds sleep
int8_t sleep_cycle_counter = 1;       // Counting how often uC woke up and blinked shortly
uint8_t isr_cnt = 0;                  // Short blink every 8 * isr_cnt seconds
uint8_t isr_cnt_to_wake_up = 2;       // How many interrupts needed to wake up (isr_cnt_to_wake_up * 8s)
int soc = 0;                          // Store SOC measurement (State of charge)
uint8_t serial_process_position = 0;  // How much of the received serial string has been processed

uint8_t mode = MODE_DEFAULT;          // Store mode
uint8_t color_r = 255;                // Store red value
uint8_t color_g = 0;                  // Store green value
uint8_t color_b = 80;                 // Store blue value
uint8_t color_w = 100;                // Store white value

uint8_t offsets[4] = {0,0,0,0};       // Store calculated offsets for smoother animation

// EEPROM
uint8_t mode_eeprom EEMEM;
uint8_t color_r_eeprom EEMEM;
uint8_t color_g_eeprom EEMEM;
uint8_t color_b_eeprom EEMEM;
uint8_t color_w_eeprom EEMEM;
uint8_t color_set_eeprom EEMEM;       // Save if color was ever set (if not, there will be a problem loading it!)
uint8_t isr_cnt_to_wake_up_eeprom EEMEM;



// ============================================================= SETUP 
void setup() {
    // Setup LED
    led.begin();
    led.show();
    
    // Setup Pins
    pinMode(PIN_MEASUREMENT, INPUT);
    pinMode(PIN_LED_ENABLE, OUTPUT);

    // Setup WDT
    cli();                          // Disable Interrupts
    wdt_reset();                    // Reset Watchdog Timer
    MCUSR &= ~(1 << WDRF);          // Disable Watchdog System Reset
    WDTCR = (1 << WDCE);            // Watchdog Change Enable
    WDTCR |= 1 << WDP0 | 1 << WDP3; // Set WDT timeout to 8 seconds
    WDTCR |= (1 << WDIE);           // Watchdog Timeout Interrupt Enable
    sei();                          // Enable Interrupts

    // Restore variables from EEPROM if they are set
    uint8_t temp_mode = eeprom_read_byte(&mode_eeprom);
    if (temp_mode != 0xFF) {
        mode = temp_mode;
    }
    if (eeprom_read_byte(&color_set_eeprom) != 0xFF) {
        color_r = eeprom_read_byte(&color_r_eeprom);
        color_g = eeprom_read_byte(&color_g_eeprom);
        color_b = eeprom_read_byte(&color_b_eeprom);
        color_w = eeprom_read_byte(&color_w_eeprom);
    }
    uint8_t temp_isr_cnt_to_wake_up = eeprom_read_byte(&isr_cnt_to_wake_up_eeprom);
    if (temp_isr_cnt_to_wake_up != 0xFF) {
        isr_cnt_to_wake_up = temp_isr_cnt_to_wake_up;
    }

    // Handle Serial communication
    handle_serial();
    
    // Calculate offsets
    offsets[POS_RED] = color_r > 0 ? 1 : 0;
    offsets[POS_GRN] = color_g > 0 ? 1 : 0;
    offsets[POS_BLU] = color_b > 0 ? 1 : 0;
    offsets[POS_WHT] = color_w > 0 ? 1 : 0;
}
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

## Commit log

2021-03-15 Added current state of the PCB design.
    [Omamori.kicad_pcb, Omamori.sch]
2021-03-15 Made changes to PCB.
    [Omamori.kicad_pcb, Omamori.sch]
2021-03-15 Split project into v1 and v2 and added missing v2 files.
    [BOM.xls, FM_own_parts.PcbLib, FM_own_parts.SchLib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]
2021-03-15 Removed old Altium outputs.
    [Necklace_pcb_Copper_Signal_Bot.gbr, Necklace_pcb_Copper_Signal_Top.gbr, Necklace_pcb_Drawing_1.gbr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]
2021-03-15 Removed all unversioned files.
    [Omamori.kicad_pcb, Omamori.sch]
2021-03-20 Chenged Arduino program and added Datasheets and Pictures.
2021-03-26 Updated Arduino program, to detect voltage of solar panels.
2021-03-27 Added a crappy Schematic lol.
2021-04-01 Improved program with LED enable pin.
2021-04-09 Modified PCB and updated Software.
    [Omamori.kicad_pcb, Omamori.sch]
2021-04-30 Updated readme, schematic and the .ino program.
2021-04-30 Changed size of v1 PCB.
2021-05-16 Updated version 2 PCB.
    [Omamori.kicad_pcb, Omamori.sch]
2021-05-17 Updated PCB layout and added gerber and pictures.
    [Omamori-B_Cu.gbr, Omamori-B_Mask.gbr, Omamori-B_Paste.gbr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]
2021-05-18 Thickened a lot of wires and ordered stuff a bit.
    [Omamori.kicad_pcb, Omamori.sch]
2021-05-18 Changed resistor position to make supercap fit.
    [Omamori.kicad_pcb]
2021-05-18 I am not sure what changed to be honest.
    [Omamori.kicad_pcb]
2021-05-18 Added a really ugly GND Polygon.
    [Omamori.kicad_pcb]
2021-05-20 Datasheet and description update as well as other minor design changes.
    [Omamori.kicad_pcb]
2021-05-24 Added reset button and changed a few wires.
    [Omamori.kicad_pcb, Omamori.sch]
2021-05-24 Updated program and modified PCB Layout to measure V_supercap.
    [Omamori.kicad_pcb, Omamori.sch]
2021-05-25 Final version + gerber export.
    [Omamori-B_Cu.gbr, Omamori-B_Mask.gbr, Omamori-B_Paste.gbr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]
2021-05-25 Beyond last second changes to the PCB design and gerber files.
    [Omamori-B_Cu.gbr, Omamori-B_Mask.gbr, Omamori-B_Paste.gbr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]
2021-05-26 Changes made to Roc1 and Roc2.
    [Omamori-B_Cu.gbr, Omamori-B_Mask.gbr, Omamori-B_Paste.gbr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]
2021-06-03 Fixed swapped resistor values.
    [bq25504_Design_Help_V1_2.xlsx]
2021-09-10 Complete overhaul of the project.
    [BOM.xls, FM_own_parts.PcbLib, FM_own_parts.SchLib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]
2021-10-28 Rename of folders.
    [BOM.xls, FM_own_parts.PcbLib, FM_own_parts.SchLib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]
2021-12-18 Updated 0.2.1 PCB design.
    [Omamori-B_Cu.gbr, Omamori-B_Mask.gbr, Omamori-B_Paste.gbr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]
2021-12-18 Updated Gerber zip.
2021-12-18 Updated images and added new solder guide.
2021-12-18 Updated pcb design and gerber files.
    [Omamori-B_Cu.gbr, Omamori-B_Mask.gbr, Omamori-B_Paste.gbr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]
2021-12-20 Layout and Design redesign.
    [Omamori-B_Cu.gbr, Omamori-B_Mask.gbr, Omamori-B_Paste.gbr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]
2021-12-20 Updated schematic image.
2021-12-21 Added pull down resistor.
    [Omamori.kicad_pcb, Omamori.sch]
2021-12-21 Minor Layout update.
    [Omamori-B_Cu.gbr, Omamori-B_Mask.gbr, Omamori-B_Paste.gbr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]
2021-12-22 Final Version of v0.2 22.12.2021.
    [Omamori-B_Cu.gbr, Omamori-B_Mask.gbr, Omamori-B_Paste.gbr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]
2021-12-22 Added Interactive BOM. Updated Gerber Files.
    [Omamori-B_Cu.gbr, Omamori-B_Mask.gbr, Omamori-B_Paste.gbr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]
2021-12-22 I don't know what changed but okay.
    [Omamori.kicad_pcb]
2021-12-22 It's the last bom gerber export I plot today, I swear lol
    [Omamori-B_Cu.gbr, Omamori-B_Mask.gbr, Omamori-B_Paste.gbr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]
2022-02-11 Created version 0.2.2 containing minor updates so far.
    [Omamori-B_Cu.gbr, Omamori-B_Mask.gbr, Omamori-B_Paste.gbr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]
2022-02-11 Removed Bom from repo.
2022-06-18 V3 update.
    [FM_own_parts.PcbLib, FM_own_parts.SchLib, Necklace.PrjPCB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]
2022-06-18 V3 restructuring.
    [bq25504_Design_Help_V1_2.xlsx, bq25505(70_Design_Help_V1_3.xlsx]
2022-06-26 Unfinished update. Serial communication still unfinished.
    [Omamori.kicad_pcb, Omamori.kicad_sch]
2022-07-04 Voltage measurement update.
    [Omamori.kicad_pcb, Omamori.kicad_sch]
2022-07-05 Updated software to measure voltage.
2022-10-01 Updated hw.
    [Omamori.kicad_pcb]
2022-10-04 Moved some parts.
    [Omamori.kicad_pcb]
2022-10-05 Temporarily finished pcb design.
    [Omamori.kicad_pcb, Omamori.kicad_sch]
2022-10-07 Updated pcb.
    [Omamori.kicad_pcb, Omamori.kicad_sch]
2022-10-07 Removed backups and changed a trace thickness.
    [Omamori.kicad_pcb]
2022-10-07 Small redesign
    [Omamori.kicad_pcb]
2022-10-08 Correct pcb design update for v3.
    [Omamori.kicad_pcb, Omamori.kicad_sch]
2022-10-08 Updated pcb image.
2022-10-09 Updated to version, which got ordered on jlcpcb.
    [Omamori-B_Cu.gbl, Omamori-B_Cu.gbr, Omamori-B_Mask.gbr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]
2022-11-01 It works! Just change 2 resistors.
    [bq25504_Design_Help_V1_2.xlsx, bq25505(70_Design_Help_V1_3.xlsx]
2022-11-10 Added HW version 0.3.1
    [Omamori-B_Cu.gbl, Omamori-B_Mask.gbs, Omamori-B_Paste.gbp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]
2022-11-17 HW Update before going to germany.
    [Omamori-B_Cu.gbl, Omamori-B_Mask.gbs, Omamori-B_Paste.gbp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]
2023-11-28 Changed v3 Firmware to use correct ADC resolution.
    [Firmware_new.ino]
2023-11-30 Firmware now has a nice button press interrupt.
2023-11-30 Fixed voltage measurement with awesome measurements. High resistance leads to weird behaviour.
    [Firmware_new.ino]
2023-12-17 Updated Omamori 0.3.1.
    [Omamori.kicad_pcb, Omamori.kicad_sch]
